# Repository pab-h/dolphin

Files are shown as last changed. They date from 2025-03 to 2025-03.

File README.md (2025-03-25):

# Dolphin

Velocimetro Digital para a minha bicicleta. Não cheguei a construí-lo por falta de material. Mas, quem quiser tentar, sinta-se livre. =)

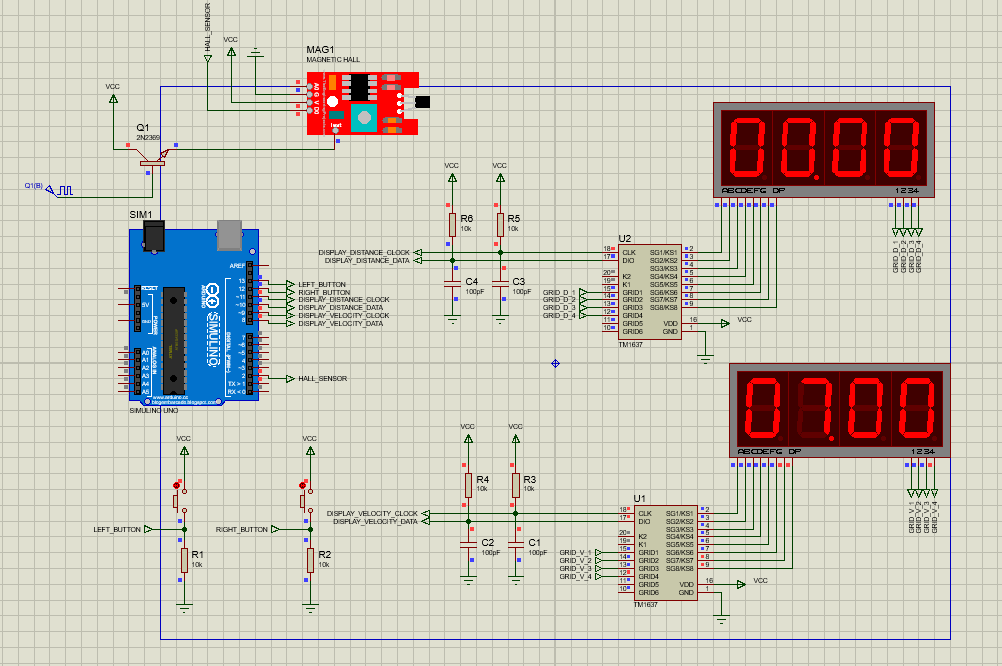
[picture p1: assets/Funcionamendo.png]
Simulação


> Para simular, foi utilizado o [Proteus 8](https://www.labcenter.com/)

## Requisitos

- [X] Medir a velocidade em Km/h;
- [X] Medir a distância percorrida;
- [X] Reiniciar a medida da velocidade (em caso de parada);
- [X] Reiniciar a distância percorrida;
- [X] Configurar o raio via software

## Materiais

- [Arduino Uno R3](https://docs.arduino.cc/hardware/uno-rev3/) 
- [Módulo TM1637 com Display 7 Segmentos 4 Dígitos](https://www.makerhero.com/produto/modulo-tm1637-com-display-7-segmentos-4-digitos/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)
- [Magnetic Hall Effect Sensor (KY-024)](https://www.eletrogate.com/sensor-de-efeito-hall-ky-024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)
- [Push Button](https://www.autocorerobotica.com.br/botao-de-toque-6x6mm)
- [Resistores 10K](https://www.autocorerobotica.com.br/resistor-de-precisao-10k-1-4w-1)

## Multifunções nos botões

- Caso o botão esquerdo for pressionado por pelo menos 1 segundos, o sistema entra em modo de configuração. Se pressionado novamente por 1 segundos, o estado é revertido;
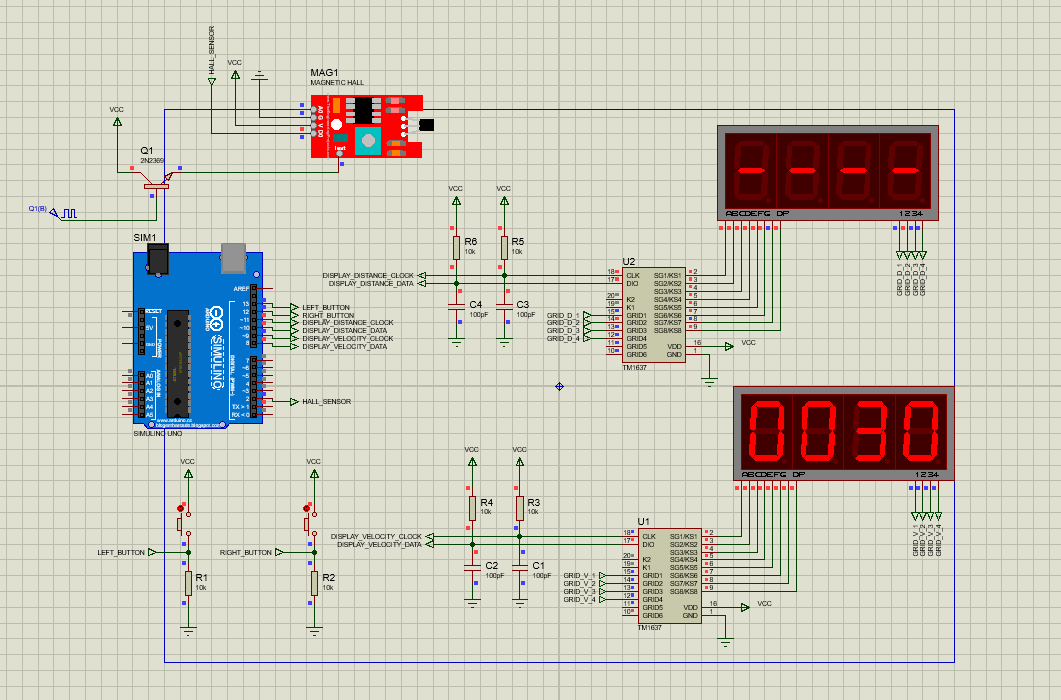
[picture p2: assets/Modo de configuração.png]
Modo de configuração


- No modo de configuração, é possível configurar o raio da roda. Botão esquerdo aumenta ao valor e o direito decrementa o valor;
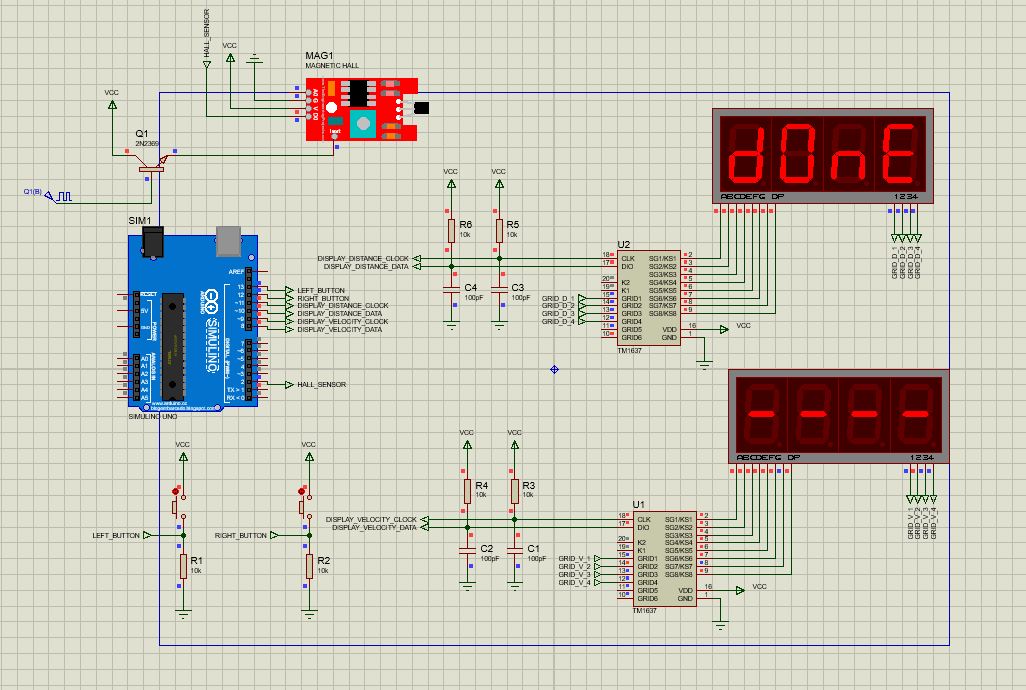
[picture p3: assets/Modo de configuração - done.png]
Saída do modo de configuração


- Se o botão direito for pressionado sem estar no estado de configuração, o hodometro é resetado;

## Esquema Elétrico e PCB

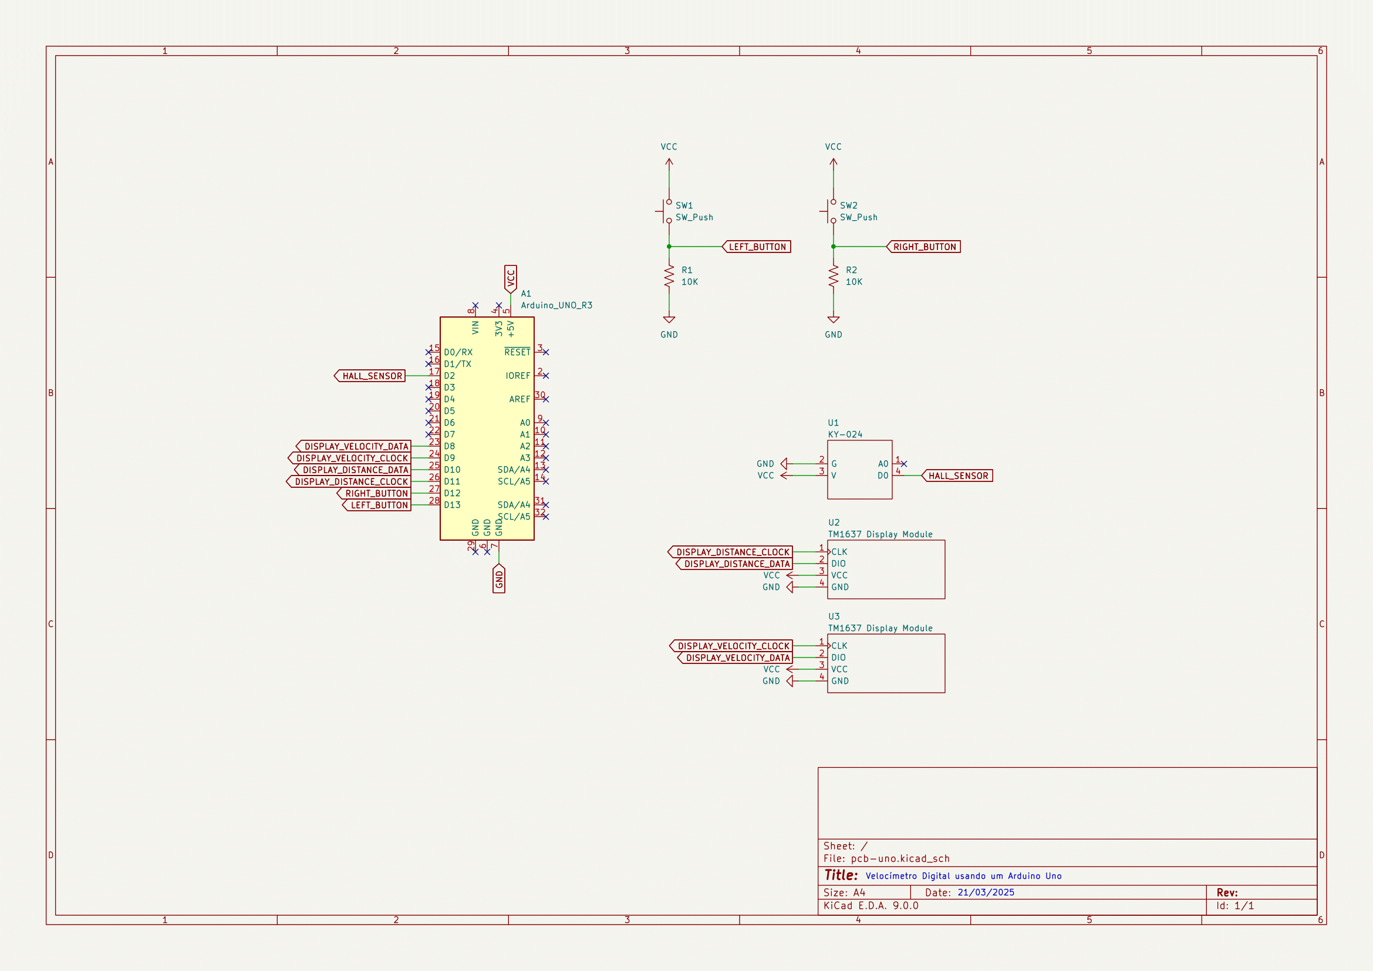
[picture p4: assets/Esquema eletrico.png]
Esquema elétrico

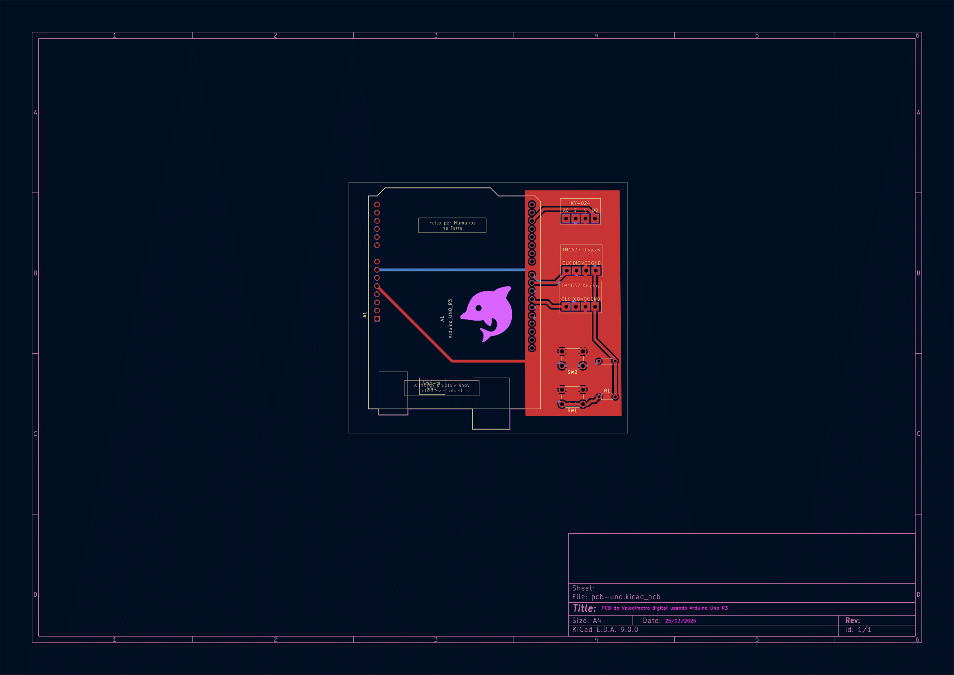
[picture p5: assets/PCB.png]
Placa de Circuito Impresso


> Para a produção dessas imagens, foi-se utilizado o software [KiCad](https://www.kicad.org/)

## Pessoalmente,

Eu gostei muito de descobrir o [PlatformIo](https://platformio.org/). Minhas sinceras felicidades para os mantenedores desse projeto. Além disso, desenvolver a implementação de um botão multifunções foi devidamente interessante. Claro, isso foi uma bela surpresa para mim. Percebi que uma abordagem orientada a eventos e a objetos foi uma descoberta no desenvolvimento desse projeto.

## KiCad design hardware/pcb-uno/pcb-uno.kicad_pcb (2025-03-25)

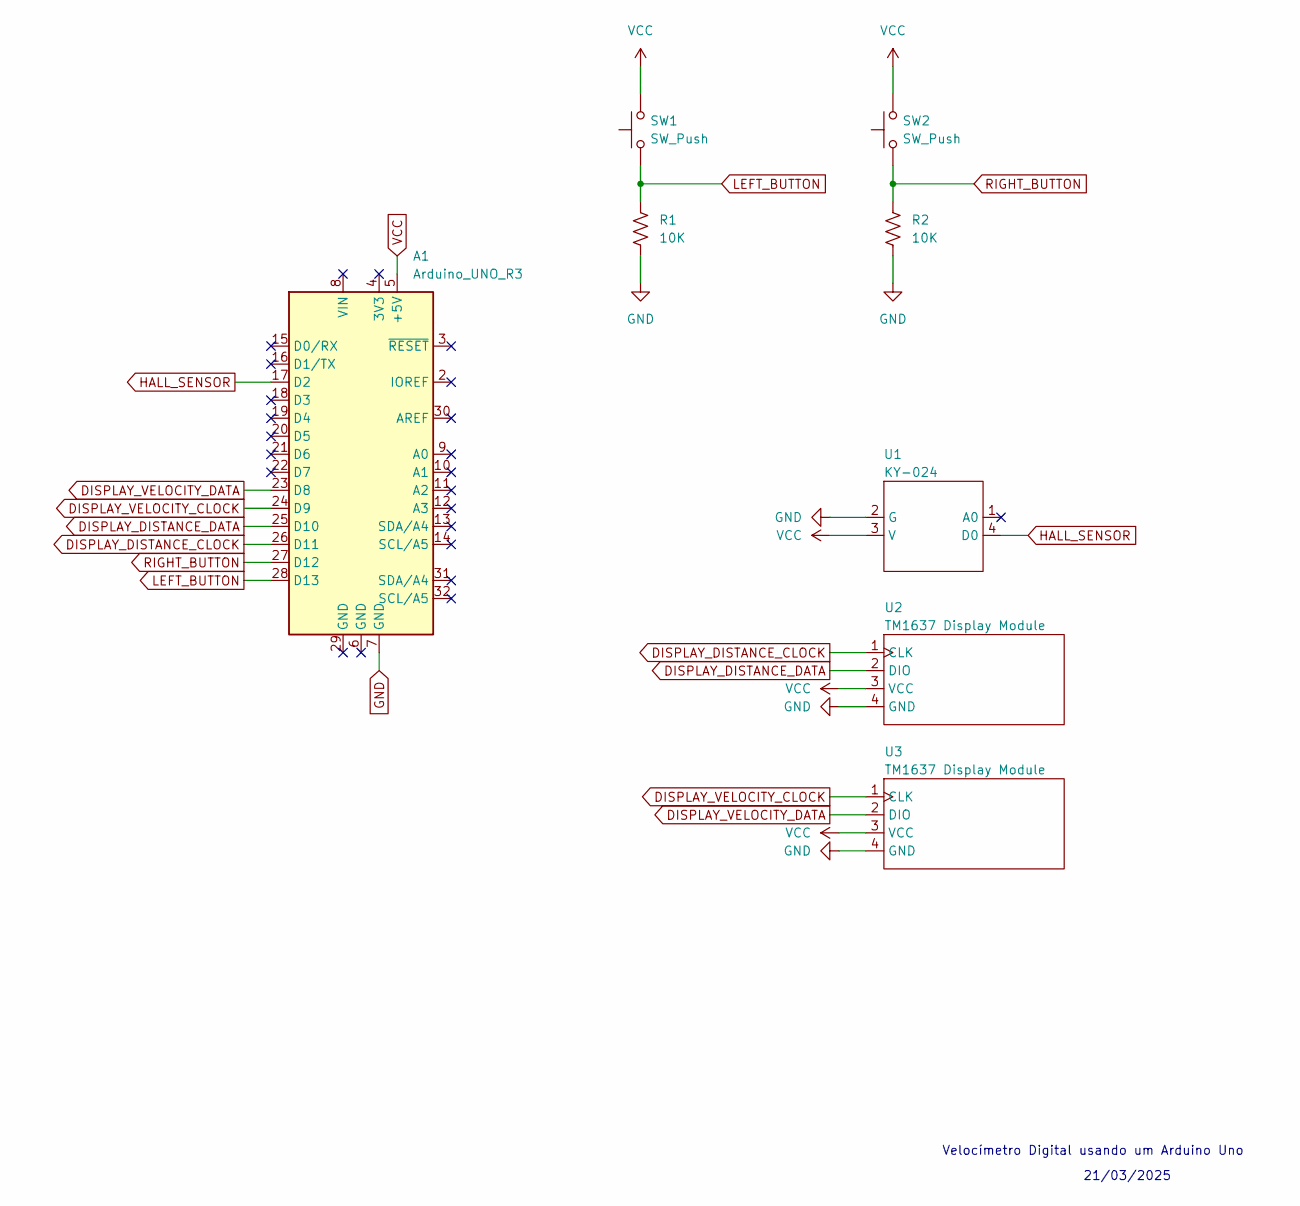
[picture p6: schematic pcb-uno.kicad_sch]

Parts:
A1: Arduino_UNO_R3
R1, R2: 10K; R_Axial_DIN0204_L3.6mm_D1.6mm_P5.08mm_Horizontal
SW1, SW2: SW_Push; SW_PUSH_6mm
U1: KY-024
U2, U3: TM1637 Display Module

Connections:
DISPLAY_DISTANCE_CLOCK: A1.26 (D11), U2.1 (CLK)
DISPLAY_DISTANCE_DATA: A1.25 (D10), U2.2 (DIO)
DISPLAY_VELOCITY_CLOCK: A1.24 (D9), U3.1 (CLK)
DISPLAY_VELOCITY_DATA: A1.23 (D8), U3.2 (DIO)
GND: A1.7 (GND), R1.2, R2.2, U1.2 (G), U2.4 (GND), U3.4 (GND)
HALL_SENSOR: A1.17 (D2), U1.4 (D0)
LEFT_BUTTON: A1.28 (D13), R1.1, SW1.1
RIGHT_BUTTON: A1.27 (D12), R2.1, SW2.1
VCC: A1.5 (+5V), SW1.2, SW2.2, U1.3 (V), U2.3 (VCC), U3.3 (VCC)

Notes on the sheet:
Velocímetro Digital usando um Arduino Uno
21/03/2025

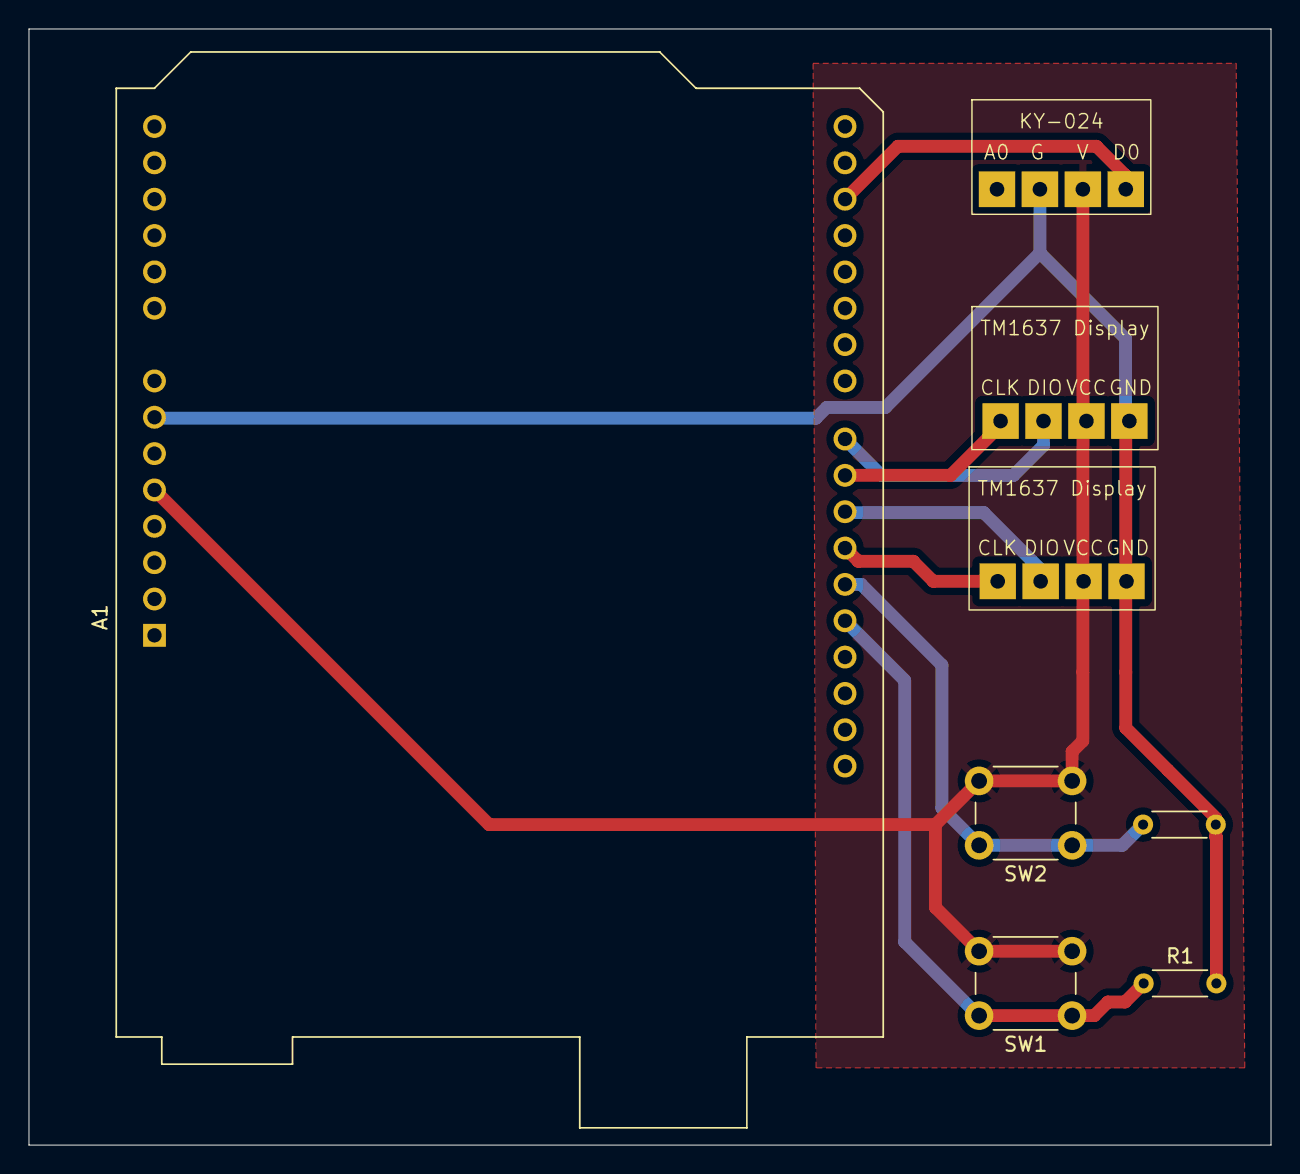
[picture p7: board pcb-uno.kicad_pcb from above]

Board: 2 copper layers, 86.8 x 78.0 mm, 8 parts (0 on the bottom side), 9 nets.

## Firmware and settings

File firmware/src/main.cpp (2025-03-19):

#include <Arduino.h>

#include "System.hpp"
#include "pins.hpp"

System& sys = System::getInstance();

void ISRHallSensorHitWrapper() {
  sys.ISRHallSensorHit();
}

void setup() {

  setupPins();

  sys.setupDisplays();

  attachInterrupt(
    digitalPinToInterrupt(HALL_SENSOR_PIN),
    ISRHallSensorHitWrapper,
    RISING 
  );

  sys.setupListeners();

}


void loop() {

  sys.run(); 

}

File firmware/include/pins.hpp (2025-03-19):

#ifndef PINS_HEADER

#define PINS_HEADER

#include <Arduino.h>

#define LEFT_BUTTON_PIN  13
#define RIGHT_BUTTON_PIN 12

#define DISPLAY_DISTANCE_CLOCK_PIN 11
#define DISPLAY_DISTANCE_DATA_PIN  10

#define DISPLAY_VELOCITY_CLOCK_PIN 9
#define DISPLAY_VELOCITY_DATA_PIN  8

#define HALL_SENSOR_PIN 2

#endif

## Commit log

2025-03-07 feat: esquemático do hardware usando o Proteus 8 para a simulação
2025-03-07 feat: mapeamento de hardware
2025-03-09 feat: arquivo de configurações
2025-03-09 feat: constantes de conversão
2025-03-09 feat: sensor hall
2025-03-09 feat: mudança nos pinos para otimizar as interrupções
2025-03-09 feat: o velocimetro
2025-03-09 feat: implementação do sensor hall
2025-03-09 faet: uso do velocimetro
2025-03-10 feat: tempo de reset do odometro
2025-03-10 feat: odometro
2025-03-10 feat: sem interrupção durante o calculo da velocidade
2025-03-10 fix: calculando os parametros dentro da interrupção para tentar mitigar o erro #5
    [main.cpp]
2025-03-10 fix: por algum motivo, não desabilitar as interrupções faz o código responder melhor ao sensor sendo simulado por um botão
2025-03-10 feat: biblioteca para TM1637
2025-03-10 feat: sensor hall na pasta de sensores
2025-03-10 feat: odometro e velocimentro na pasta dos medidores
2025-03-10 feat: display de distância
2025-03-10 feat: display de velocidade
2025-03-10 feat: utilizando um pulso de clock para simular o sensor hall
2025-03-15 feat: limiares para click e pressionar no botão
2025-03-15 fix: o hodometro não deve ser resetado sem que o usuário queira
2025-03-15 refactor: limitar de reset no arquivo de configurações
2025-03-15 refactor: tipo mais adequado para o número do pino
2025-03-15 feat: Classe PushButton - lidar com clicks - lidar com pressionar o botão por 1 segundo (ou mais)
2025-03-17 feat: código base para a escrita do raio na EEPROM
2025-03-18 refactor: nome apropriado para o atributo no construdor do hodometro
2025-03-18 feat: classe que representa o sistema
2025-03-19 refactor: tipo mais adquado para o número dos pinos
2025-03-19 feat: display de configuração
2025-03-19 feat: botão de resertar o hodometro
2025-03-25 feat: PCB
    [pcb-uno.kicad_pcb, pcb-uno.kicad_sch]
